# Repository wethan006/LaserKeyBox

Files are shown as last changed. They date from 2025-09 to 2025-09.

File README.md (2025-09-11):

# LaserKeyBox
Contains all the information for my laser key box. Its a simple lock box that holds a key. Made using what I had around: a Raspberry pi 1, Arduino Uno R3, Servo Motor, Limit Switch, LEDs, Active Buzzer, Magnets, Card Reader, RFID reader, and PLA.

# Raspberry Pi
I had to install the evdev library for this, and you'll have to change your text file name and log file name. Note that I set up the start script and logging using crontab on the pi.

# Design
How it all gets wired is up to you if you were to make it, such as changing which pins are used, but here I'll explain what is connected to what. The card reader and arduino are connected to the raspberry pi using usb cables, the buzzer+ is connected to a 220 ohm resistor then the arduino, all three LEDs are the same. The limit switch, RFID, and servo motor are connected to the arduino. The fan+ is connected to arduino 5v, fan- is connected to an NPN collector then a 220 ohm resistor connected to the NPN base and the resistor to arduino pin. I am using a pwm pin for the fan so I can control the speed. I have a small bread board inside of the box making all of these connections, if you use the same method be sure to use cables over 3inches.

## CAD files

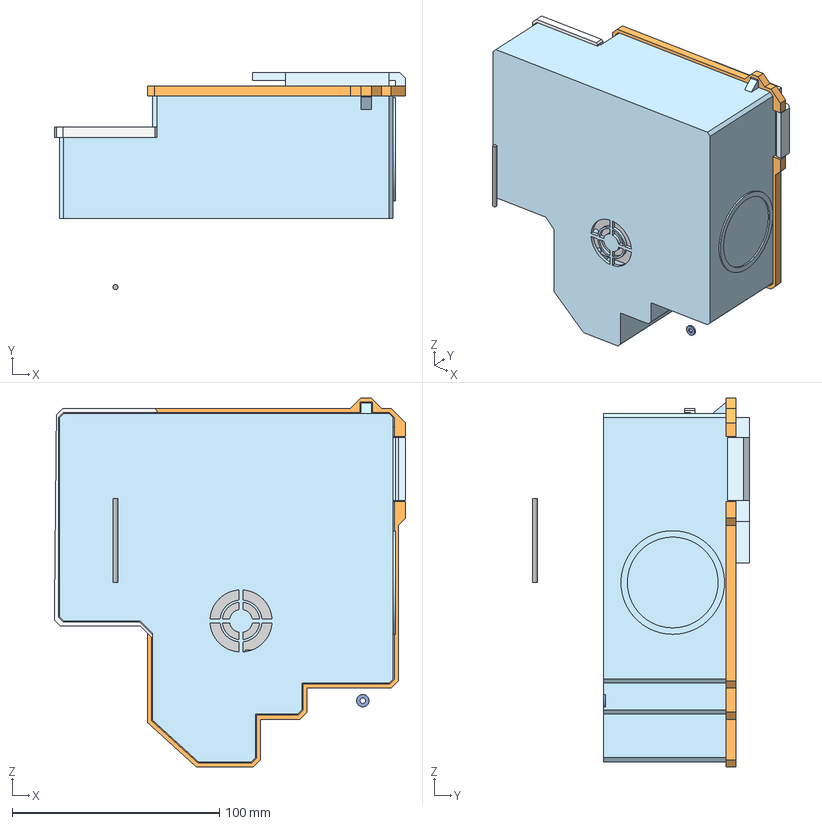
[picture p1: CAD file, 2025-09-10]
3D Parts/KeyBox.step
169.5 x 104.9 x 178.0 mm

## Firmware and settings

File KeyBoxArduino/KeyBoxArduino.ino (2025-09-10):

#include <Servo.h> //adds servo motor library
#include <SPI.h> //SPI coms
#include <MFRC522.h> 
#define RST_PIN 8 //sets the reset pin to reset
#define SS_PIN 10 //SDA (SS) pin connected

//objects
Servo myservo; //creates a servo motor object to control
MFRC522 rfid(SS_PIN, RST_PIN);

const String UPDATE_MODE = "UPDATE_MODE";
//pins
const int SERVOPIN = 9; //the connected pin for orange cable can be 9 or 10 digital
const int LIMITSWITCHPIN = A4; //sets the limit switch pin
const int LOCKEDANGLE = 0;
const int UNLOCKEDANGLE = 90;
const int BUZZERPIN = A3; //connects to the positive side of the buzzer
const int GREENLEDPIN = A0; //the pin for LEDS, can be 13,12,11
const int YELLOWLEDPIN = A1; //used to show that ID adding is on
const int REDLEDPIN = A2;
const int FANPIN = 6;
//analog outputs A0-A5
//RFID, NUMBER
const byte masterUID[] = {0xCB, 0xCE, 0xE2, 0x1A}; //must be prefixed with 0x for byte 0x1A
//sets the ready for action
boolean ready = false;

void setup() {
  // put your setup code here, to run once: 
  while (!Serial); //wait for serial connection to open
  Serial.begin(9600); //connect serial to raspberry pi
  //sets the servo lock
  myservo.attach(SERVOPIN); //connects the object to the signal pin
  myservo.write(LOCKEDANGLE); //inital position of the motor should be the lock position
  //sets the limit switch
  pinMode(LIMITSWITCHPIN, INPUT_PULLUP); //uses the internal pullup resistor for the limitswitch
  //sets the buzzer
  pinMode(BUZZERPIN, OUTPUT); //sets the output pin for the buzzer
  digitalWrite(BUZZERPIN, LOW); //this sets the buzzer to off in the beginning
  //sets the LED pins
  pinMode(GREENLEDPIN, OUTPUT); //sets pin to output
  digitalWrite(GREENLEDPIN, HIGH); //green is on, showing system ready
  pinMode(YELLOWLEDPIN, OUTPUT);
  digitalWrite(YELLOWLEDPIN, HIGH);
  pinMode(REDLEDPIN, OUTPUT);
  digitalWrite(REDLEDPIN, HIGH);
  //RFID
  SPI.begin(); //start SPI
  rfid.PCD_Init(); //start object
  ready = false;
  //fan pin
  pinMode(FANPIN, OUTPUT);
  analogWrite(FANPIN, 50);
}

void loop() {
  // put your main code here, to run repeatedly:
  while(!ready) {
    String piConnected = Serial.readStringUntil('\n');
    piConnected.trim();
    if(piConnected.length() > 0) {
      if(piConnected == "PI_READY"){
        digitalWrite(YELLOWLEDPIN, LOW);
      } if (piConnected == "RFID_READY") {
        digitalWrite(REDLEDPIN, LOW);
        ready = true;
      }
    } 
  }
  
  String openLock = Serial.readStringUntil('\n'); //read output from pi until new line
  openLock.trim(); //gets rid of whitespace
  if(openLock.length() > 0) { //if the input has any length to it, if not here the serial input will keep printing
    if(openLock == "OPEN_LOCK") {
      Serial.println("Lock is opening");
      myservo.write(UNLOCKEDANGLE); //turns 90 degrees
      //controls the buzzer
      digitalWrite(BUZZERPIN, HIGH); //on
      delay(400);
      digitalWrite(BUZZERPIN, LOW); //Sound will turn off on its own, but the pin will not, this turns it off
      digitalWrite(YELLOWLEDPIN, HIGH);
      //cycles green led until the door is opened then turns off green led
      while(digitalRead(LIMITSWITCHPIN) == LOW) {
        digitalWrite(GREENLEDPIN, LOW);
        delay(200);
        digitalWrite(GREENLEDPIN, HIGH);
        delay(200);
      }
      digitalWrite(GREENLEDPIN, LOW);
    } else { //door not open 
      digitalWrite(REDLEDPIN, HIGH); //red light on
      for (int i = 0; i < 3; i++) {
        digitalWrite(BUZZERPIN, HIGH); //on
        delay(100);
        digitalWrite(BUZZERPIN, LOW); //off
        delay(100);
      }
      digitalWrite(REDLEDPIN, LOW); //red light off
    }
  }

  //auto locks the box
  if (digitalRead(LIMITSWITCHPIN) == LOW) { //LOW means pressed, HIGH means not pressed
    delay(50); //adds a small delay for the switch then will check again, bounce check
    if (digitalRead(LIMITSWITCHPIN) == LOW) {
      myservo.write(LOCKEDANGLE);
      digitalWrite(YELLOWLEDPIN, LOW);
      digitalWrite(GREENLEDPIN, HIGH); //turns green light back on
    }
  }
  
  //RFID
  if(rfid.PICC_IsNewCardPresent() && rfid.PICC_ReadCardSerial()) { //start of RFID if
    boolean authorized = false;
    //read and compare to master card designed so all you need to change is the masterUID for this to work
    if (rfid.uid.size == sizeof(masterUID)) {
      for(int i = 0; i < rfid.uid.size; i++) {
        if(memcmp(rfid.uid.uidByte, masterUID, sizeof(masterUID)) == 0){
          authorized = true;
        } else { //if any of the bytes do not match the boolean is false
          authorized = false;
          break;
        }
      }
    }
    //if the door is closed but was just swipped to open, which turns the yellow led on, the rfid will not work
    if (authorized && digitalRead(LIMITSWITCHPIN)==LOW && digitalRead(YELLOWLEDPIN)==HIGH){
      authorized = false;
    }
    else if (authorized && digitalRead(LIMITSWITCHPIN)==LOW) { //switching to update ID list mode
      Serial.println(UPDATE_MODE); //sends the update string to the raspberry PI
      rfid.PICC_HaltA(); //Halt PICC
      while(authorized) {
        String updateReady = Serial.readStringUntil('\n'); //scans for update ready message from PI
        updateReady.trim(); //gets rid of whitespace
        if(updateReady.length() > 0) {
          if(updateReady == "UPDATE_READY") {
            digitalWrite(YELLOWLEDPIN, HIGH); //turns on yellow light
            for (int i = 0; i < 5; i++) {
              digitalWrite(BUZZERPIN, HIGH); //on
              delay(100);
              digitalWrite(BUZZERPIN, LOW); //off
              delay(100);
            }
          }
          if(updateReady == "EXIT_UPDATE") {
            digitalWrite(BUZZERPIN, HIGH);
            delay(400);
            digitalWrite(BUZZERPIN, LOW);
            authorized = false;
          }
        }
      }
      digitalWrite(YELLOWLEDPIN, LOW); //turns off yellow led
    } //updatemode if
    //controls delete mode
    //checks if the door is open and yellow led is on and green led is off
    else if (authorized && digitalRead(LIMITSWITCHPIN)==HIGH && digitalRead(YELLOWLEDPIN)==HIGH && digitalRead(GREENLEDPIN)==LOW){
      boolean deleteMode = true;
      digitalWrite(REDLEDPIN, HIGH); //turns on red led
      //beep twice
      for(int i = 0; i < 2; i++){
        digitalWrite(BUZZERPIN, HIGH);
        delay(100);
        digitalWrite(BUZZERPIN, LOW);
        delay(100);
      }
      Serial.print("DELETE_MODE");
      while (deleteMode){
        String deleteComplete = Serial.readStringUntil('\n');
        deleteComplete.trim();
        if(deleteComplete.length()>0 && deleteComplete == "ID_RESET_COMPLETE"){
          deleteMode = false;
          authorized = false;
          digitalWrite(REDLEDPIN, LOW);
          digitalWrite(BUZZERPIN, HIGH);
          delay(100);
          digitalWrite(BUZZERPIN, LOW);
        }
      }
    }
    /*
    //Use this section of code for getting the RFID of a new tag card
    if ( ! rfid.PICC_IsNewCardPresent()) { //look for new cards
      return;
    }

    if (! rfid.PICC_ReadCardSerial()) {
      return;
    }

    Serial.print("Card UID:");
    for(byte i = 0; i < rfid.uid.size; i++) {
      Serial.print(rfid.uid.uidByte[i] < 0x10 ? " 0" : " ");
      Serial.print(rfid.uid.uidByte[i], HEX);
    }
    Serial.println();

    rfid.PICC_HaltA(); 
    */
  } //end of RFID if
}

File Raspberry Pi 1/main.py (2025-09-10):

#!/usr/bin/env python3


from evdev import InputDevice, categorize, ecodes, KeyEvent, list_devices
import select
import time
import serial
import serial.tools.list_ports # for reading the available ports
import os
import datetime

#hex numbers for rfid reader found using lsusb
RFID_VENDOR_ID = 0x0801
RFID_PRODUCT_ID = 0x0001

#hex numbers for arduino found using lsusb
ARDUINO_VENDOR_ID = 0x2341
ARDUINO_PRODUCT_ID = 0x0043

#const values
SCRIPT_PATH = os.path.dirname(os.path.abspath(__file__))
LOG_FILENAME = os.path.join(SCRIPT_PATH, "keybox_log.txt")
ID_FILENAME = os.path.join(SCRIPT_PATH, "idlist.txt")
BAUD_RATE = 9600
TIMEOUT = 1

#used for reading the ID list txt file change file name if ever changing
def read_authorized_ids(filename):
	try:
		with open(filename, "r") as f:
			listArray = [line.strip().split('_')[0] for line in f if line.strip()]
	except FileNotFoundError:
		print(f"Read File not found {filename}")
		return None
	return listArray
	
#used to find the rfid reader and make arduino connection
def find_device(vendor_id, product_id):
	#trys arduino connection first
	try:
		arduino_port = None
		ports = list(serial.tools.list_ports.comports())
		for p in ports:
			#checks for the vender id and product
			if p.vid == vendor_id and p.pid == product_id:
				arduino_port = p.device
				break;
		#if arduino port is not None
		if arduino_port:
			print(f"Found Arduino on Port: {arduino_port}")
			ardConnection = serial.Serial(arduino_port, BAUD_RATE, timeout=TIMEOUT)
			ardConnection.reset_input_buffer()
			print("Arduino connected!")
			return ardConnection
	except serial.SerialException as s:
		print(f"Serial fail error {s}")
	except Exception as e:
		print(f"Unknown error as serial connection {e}")
		
	if arduino_port == None:
		devices = [InputDevice(path) for path in list_devices()] #looks at all devices plugged in
		for device in devices:
			if device.info.vendor == vendor_id and device.info.product == product_id:
				#if the arduino was not found this will return nothing
				if vendor_id == ARDUINO_VENDOR_ID and product_id == ARDUINO_PRODUCT_ID:
					return None
				return device
		print("device not found trying again")
		return None

#used for writing the file
def write_to_file(newTextArray, filename):
	try:
		with open(filename, "w") as f:
			for newString in newTextArray:
				f.write(f"{newString}\n")
	except IOError as e:
		print(f"There was an IO error: {e}")

#use to clear the log file and stop from getting to big
def clear_logs(filename):
	logList = read_authorized_ids(filename)
	if len(logList) > 20:
		newLogList = logList[len(logList)-1]
		write_to_file(newLogList, filename)
#main function running the program
def main():
	#gets ids from stored file exits program on error
	errNumber = 0
	while True:
		authorized_ids = read_authorized_ids(ID_FILENAME)
		if authorized_ids == None:
			print(f"Error:{errNumber} ID file is not working or opening retrying in 5 seconds")
			errNumber += 1
			time.sleep(5)
		else:
			errNumber = 0
			break
			
	#sets a blank update tag to use
	update_tag_id = ""
	
	#do while statment for getting arduino connection
	while True:
		ardConnection = find_device(ARDUINO_VENDOR_ID, ARDUINO_PRODUCT_ID)
		if ardConnection == None:
			print(f"Error:{errNumber} Arduino is not connected will try again in 5 seconds")
			errNumber += 1
		else:
			print("Arduino found continuing")
			time.sleep(3)
			ardConnection.write(b"PI_READY")
			errNumber = 0
			break
		#wait five seconds before trying again
		time.sleep(5)
		
	#do while statment for getting rfid connection
	while True:
		rfid_device = find_device(RFID_VENDOR_ID, RFID_PRODUCT_ID)
		if rfid_device == None:
			print(f"Error:{errNumber} RFID not connected trying agian in five seconds")
			errNumber += 1
		else:
			print("RFID found continuing")
			#incase arduino is not ready for input
			time.sleep(2)
			ardConnection.write(b"RFID_READY")
			errNumber = 0
			break
		#wait five seconds
		time.sleep(5)
		
	#try statement for getting card tag and comparing it
	try:
		#grabs the reader so that it cant print to notepad
		rfid_device.grab()
		print("Listening for ID swipe or Arduino Messages")
		current_tag_id = ""
		#boolean value for update mode
		update_mode = False
		update_tag_id = ""
		
		while True:
			#adds the date for today
			dayObject = datetime.datetime.now()
			dayString = dayObject.strftime("%d%B%Y_%H:%M")
			
			r, w, x = select.select([rfid_device.fd, ardConnection.fileno()], [], [], 0.1)
			#if r means if read
			if r:
				if rfid_device.fd in r:
					for event in rfid_device.read():
						if event.type == ecodes.EV_KEY:
							key_event = categorize(event)
							if key_event.keystate == KeyEvent.key_down:
								if key_event.keycode == 'KEY_KPENTER' or key_event.keycode == 'KEY_ENTER':
									if current_tag_id:
										current_tag_id = current_tag_id.strip(';?').strip()
										print(f"Detected RFID: {current_tag_id}")
										#starts update_mode for adding a tag
										if update_mode:
											update_tag_id = (current_tag_id + "_" + dayString)
											print(f"Adding ID: {update_tag_id} to list")
											authorized_ids.append(update_tag_id)
											write_to_file(authorized_ids, ID_FILENAME)
											#wait 3 seconds for the file to save and close
											time.sleep(3)
											#resets everything
											update_mode = False
											authorized_ids = read_authorized_ids(ID_FILENAME)
											ardConnection.write(b"EXIT_UPDATE\n")
											time.sleep(3)
										else:
											if current_tag_id in authorized_ids:
												print("Access Granted!")
												ardConnection.write(b"OPEN_LOCK\n")
												#waits 3 seconds for arduino response
												time.sleep(3)
												response = ardConnection.readline().decode('ascii').strip()
												print(f"Arduino Response: {response}")
											else:
												print("Access Denied!")
												ardConnection.write(b"NO_ACCESS\n")
									#resets the current tag
									current_tag_id = ""
									#clears the logs
									clear_logs(LOG_FILENAME)
								elif key_event.keycode.startswith('KEY_'):
									key_char = key_event.keycode.replace('KEY_', '')
									if key_char.isdigit():
										current_tag_id += key_char.lower()
									else:
										pass
				#Arduino Message Received
				if ardConnection.fileno() in r:
					try:
						arduino_message = ardConnection.readline().decode('ascii').strip()
						print(f"Arduino sent: {arduino_message}")
						if arduino_message == "UPDATE_MODE":
							print("Arduino wants to change to update mode")
							update_mode = True
							time.sleep(3)
							ardConnection.write(b"UPDATE_READY\n")
						if arduino_message == "DELETE_MODE":
							#deletes the current IDs stored by usingan empty string
							print("Deleting all IDs, and logs")
							emptyArray = []
							write_to_file(emptyArray, ID_FILENAME)
							time.sleep(3)
							write_to_file(emptyArray, LOG_FILENAME)
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

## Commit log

2025-09-10 Arduino Sketch Files
    Added Arduino sketch files currently in use
2025-09-10 Raspberry Pi files
    Python file for the raspberry pi 1 does not include text files for the log or id list, and does not include how to setup file to run on start.
2025-09-10 3D Parts File
    There are seven parts, included in the step file. I used onshape
    [KeyBox.step]
